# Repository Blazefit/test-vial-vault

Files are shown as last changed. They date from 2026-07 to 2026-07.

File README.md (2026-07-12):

# Testosterone Vial Vault — dark room-temp storage

3D-printable, **light-blocking** storage for testosterone vials + syringes, kept at **room
temperature** (not fridge/freezer). Three sizes at different capacities — **pick one**.

Every pocket is a cell in a **fused honeycomb**: the cell walls overlap and join into one
continuous structure (nothing is a free-standing tube that can snap off), and each cell is
only as **tall as its own vial** so the block stays light. Print in an opaque dark filament
and add the lift-off lid — every vial sits shaded in its own opaque cell.

> **Engineering models, not medical advice.** Verify vial fit with calipers before printing a
> full set (see `PARAMS.md`).

---

## Pick a design

| | **A — Compact** | **B — Standard** | **C — Max** |
|---|---|---|---|
| 10 mL vials | 6 | 8 | 10 |
| 30 mL vials | 3 | 4 | 5 |
| 1 mL vials | 24 | 30 | 36 |
| Syringes (2×N) | 4 | 4 | 6 |
| **Total openings** | **37** | **46** | **57** |
| Block (in) | 6.07 × 6.44 × 3.58 | 7.57 × 6.44 × 3.58 | 8.03 × 7.30 × 3.58 |
| Block (mm) | 154 × 164 × 91 | 192 × 164 × 91 | 204 × 186 × 91 |
| Fits 220 mm bed | ✓ | ✓ | ✓ |
| Light-tightness | genus 0 (sealed) | genus 0 | genus 0 |
| ~PETG tray+lid @15% | ~330 g | ~400 g | ~460 g |

Renders: `renders/{A,C}_top.png` (layout), `{A,C}_tray.png` (3/4), lids, and the fit-audit
cutaway `renders/C_section.png`.

## Why it's strong now (the honeycomb + reinforcement)
The earlier revision used individual tubes with gaps between them — interior tubes were
cantilevered off the base and **snapped off**. This revision packs the cells so their 2 mm
walls **overlap by ~1 mm and fuse** into a continuous honeycomb (verified: every pocket's
nearest neighbour overlaps, `tube-fuse margin = −1.0 mm`). Edge cells fuse into the perimeter
wall; a 5 mm solid base ties every cell bottom together. There are no free-standing walls.

**Reinforced against cold snapping** (the two failure points if it's dropped when cold):
- **Fillet at every cell-to-base junction** (`FILLET = 2.5 mm`, 45°) — spreads the load out of
  the sharp root corner where a wall would otherwise crack off. This is the single biggest
  anti-snap change.
- **Perimeter wall thickened 3 → 4 mm** — it's the tallest thin wall and takes the drops.
- Cost of both: only ~25 g more filament.

**Material matters more than geometry for cold brittleness:** print in **PETG** (tough, stays
that way cold), **not PLA** (PLA is what snaps when cold). If it lives somewhere genuinely cold,
PETG or ASA. Use **4 wall/perimeter lines** in the slicer — the honeycomb's strength is in its walls.

## Why every vial stays dark
1. **Opaque filament** (print black/dark) — walls don't transmit light.
2. **Own opaque cell** — each vial is walled on all sides; the cell rim sits ~8 mm above the
   vial top.
3. **Solid base + perimeter wall + lift-off lid** — the box is closed on all six sides;
   genus 0 means there is not a single through-hole in any wall.

## Stepped cells = lighter
Each cell is only `vial height + 8 mm` tall, so a 45 mm 1 mL vial gets a ~53 mm cell instead
of riding a tall dead pedestal up to the 91 mm rim. That cut the print mass by ~60 % versus a
solid block, while keeping full honeycomb strength.

## Print settings
- **Material:** **PETG** in an **opaque dark color** — light-blocking + cold-tough. Avoid PLA if
  it will ever be cold (that's what snaps).
- **Infill:** 12–15 %. **Walls/perimeters: 4** (the honeycomb strength lives in the walls).
- **Supports:** none. Print tray base-down, lid **roof-down** (skirt up).
- **Bed:** ≤ 220 × 220 mm covers all three. Bore mouths are chamfered for easy drop-in.

## Files
```
scad/vial_vault.scad   parametric model (tray | lid | section) — reads build/<D>_geom.scad
tools/layout.py        layout + geometry engine + all checks (edit fit params HERE)
tools/build_all.sh     render every design to stl/ + renders/
tools/verify_bbox.py   parse STL: bbox match, mesh volume, mass
build/                 auto-generated per-design geometry + part wrappers
stl/  renders/         print files + images
PARAMS.md              every dimension in mm + inches, with the fit assumptions
LOG.md                 iteration log + geometry-check summary
```

## Regenerate / retune
```bash
# edit vial sizes / counts in tools/layout.py, then:
python3 tools/layout.py all      # runs all geometry checks, writes build/
bash   tools/build_all.sh        # renders stl/ + renders/
python3 tools/verify_bbox.py stl/C_tray.stl   # bbox + mass sanity
```

## Verification (final)
All 6 parts render **manifold / NoError**, **genus 0** (no wall openings), and rendered bbox
**matches** the computed envelope. Geometry checks pass: shared webs ≥ 3 mm, every cell fuses
a neighbour or the wall (no free-standing tubes), all pockets inside the faces, tray+lid fit
the bed, 5 mm base under every vial, vials recessed 8 mm. See `LOG.md`.

## Fit status
- **10 mL 21.7 mm · 30 mL 33.1 mm — caliper-verified** (2026-07-12); bores 23.7 / 35.1 mm at a
  1.0 mm radial gap.
- **1 mL 16.0 mm · syringe 14 mm bore × 65 mm — still assumed** (barrel/short syringe, needle off).
  Calipers welcome; both are one-line edits in `tools/layout.py`. Details: `PARAMS.md`.

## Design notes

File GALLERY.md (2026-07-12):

# Vial Vault — Render Gallery

Fused stepped-honeycomb designs, **reinforced against cold snapping** (45° fillet at every
cell-to-base junction + 4 mm perimeter wall). Render colors are the OpenSCAD preview
(teal/blue = walls, orange = interior) — print in **opaque dark PETG** (not PLA — PLA snaps
when cold), 4 wall lines, 15 % infill. All three are 91 mm / 3.58 in tall, fit a 220 mm bed,
and are fully light-tight (genus 0).

---

## A — Compact Honeycomb ⭐ chosen to print
**37 cells:** 6×10 mL · 3×30 mL · 24×1 mL · 4 syringe — **154 × 164 × 91 mm (6.07 × 6.44 × 3.58 in)** — ~320 g PETG
*(10 mL & 30 mL fits caliper-verified 2026-07-12)*

Top-down (layout):
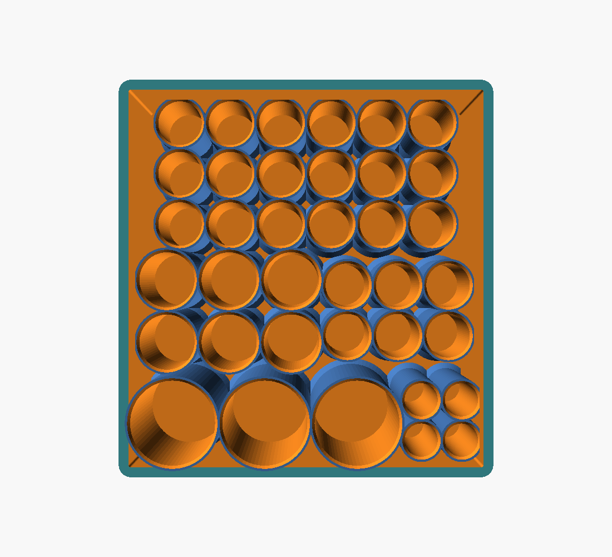
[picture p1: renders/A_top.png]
A top-down


3/4 view (fused honeycomb):
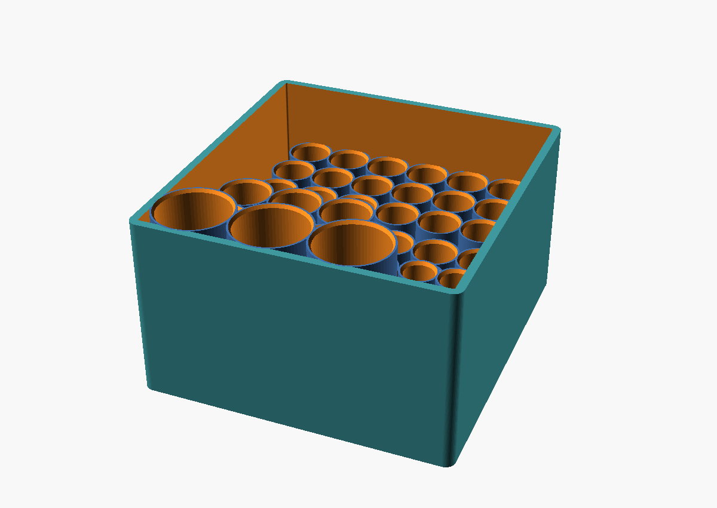
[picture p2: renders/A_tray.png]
A 3/4


Cutaway — vials rest on the base, each in its own cell (red = reference vials):
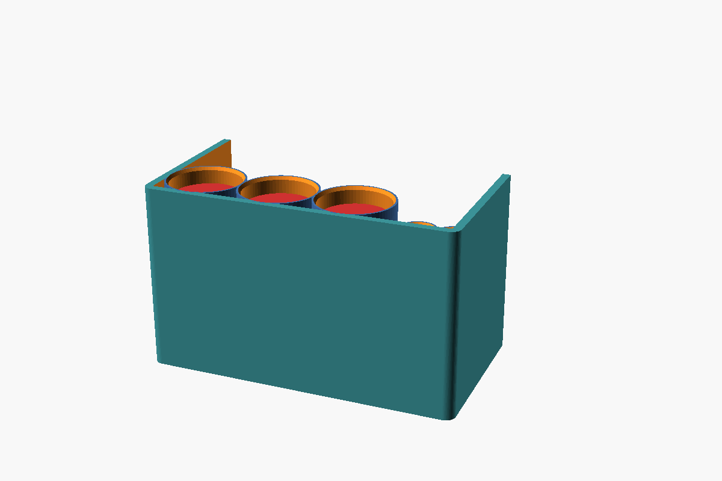
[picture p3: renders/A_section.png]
A cutaway


Lid (prints roof-down):
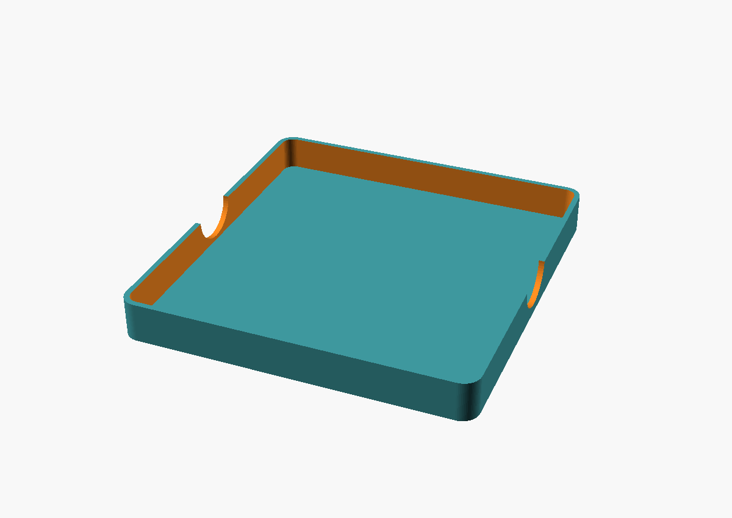
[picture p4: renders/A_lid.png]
A lid


---

## B — Standard Honeycomb
**46 cells:** 8×10 mL · 4×30 mL · 30×1 mL · 4 syringe — **192 × 166 × 91 mm (7.56 × 6.54 × 3.58 in)** — ~400 g PETG

Top-down (layout):
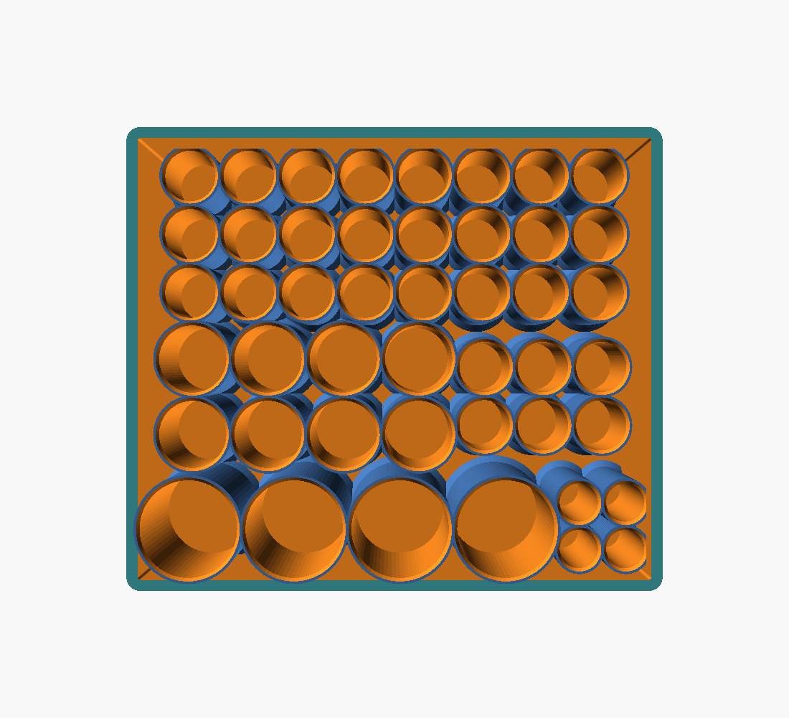
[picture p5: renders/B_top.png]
B top-down


3/4 view:
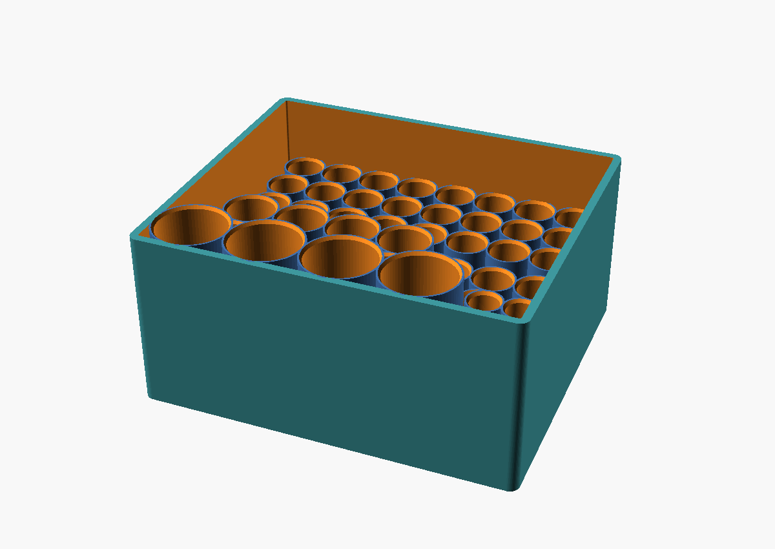
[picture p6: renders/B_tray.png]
B 3/4


---

## C — Max Honeycomb
**57 cells:** 10×10 mL · 5×30 mL · 36×1 mL · 6 syringe — **204 × 188 × 91 mm (8.03 × 7.40 × 3.58 in)** — ~460 g PETG

Top-down (layout):
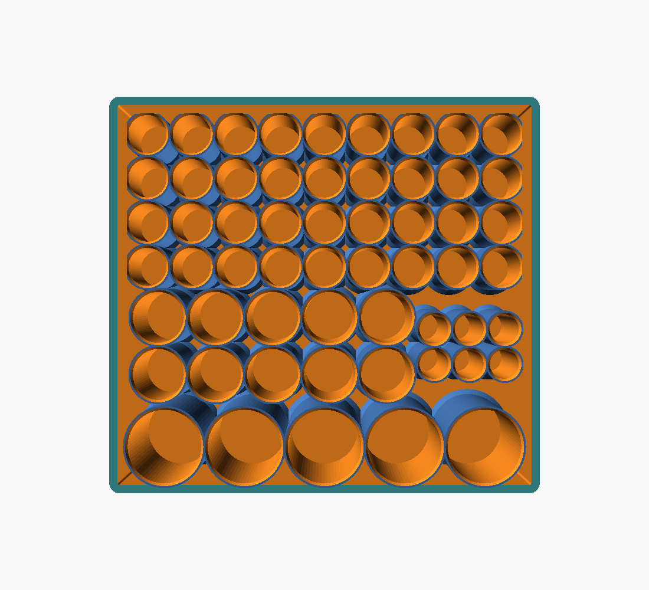
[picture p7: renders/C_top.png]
C top-down


3/4 view (stepped honeycomb):
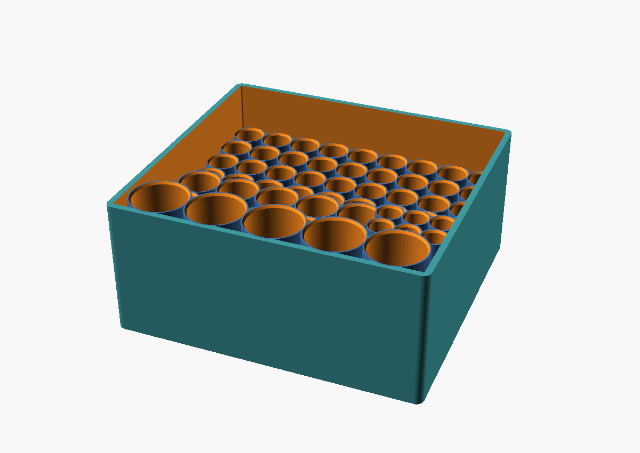
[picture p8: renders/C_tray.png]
C 3/4


Cutaway — vials rest on the base, each in its own cell (red = reference vials):
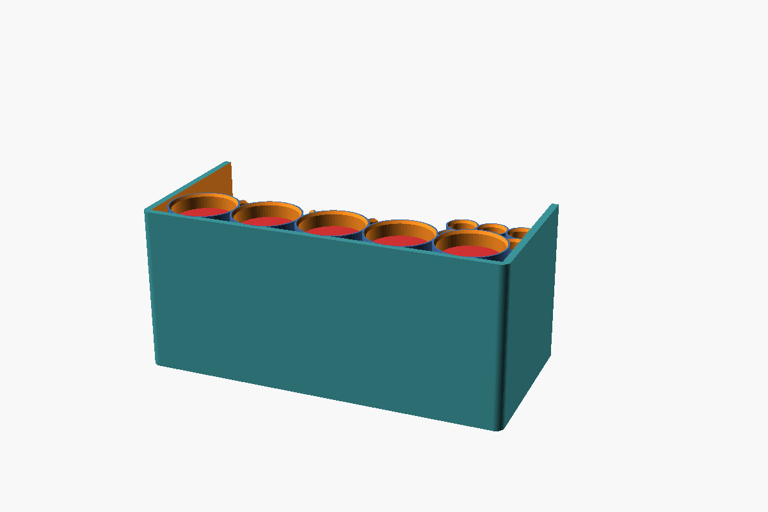
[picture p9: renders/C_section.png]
C cutaway


Lid (prints roof-down):
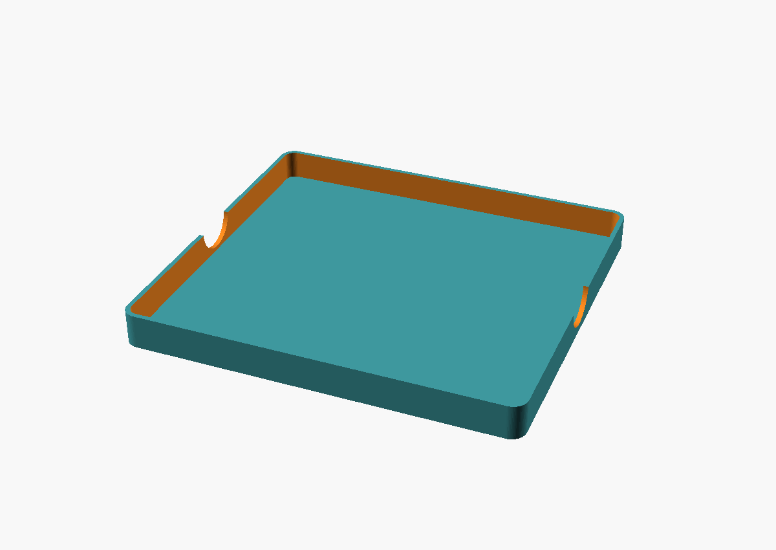
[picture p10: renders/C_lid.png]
C lid


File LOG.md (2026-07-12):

# Iteration Log — Testosterone Vial Vault

Every iteration is gated by `tools/layout.py` (analytic geometry checks) and, where
geometry changed, by `tools/verify_bbox.py` against the freshly rendered STL. "PASS"
means all HARD checks cleared for A, B, and C.

| # | Change | Problem it fixed / why | Result |
|---|---|---|---|
| 1 | Initial row-packed layout + geometry checker | baseline | **FAIL** — 30 mL pedestals 2.0 mm (< 4.0 min); Design C 236 mm long (> 220 bed) |
| 2 | `rim_height` += `INNER_GAP`; rebalanced C (1 mL → 6 cols) | pedestal math dropped the 2 mm bore-bottom gap; C overran bed | **PASS** all three |
| 3 | Rendered STLs, bbox-verified vs computed envelope; C 10 mL → single row of 6 | C lid was 218.4 mm (1.6 mm bed margin — fragile); bbox parser guards silent wrong-part renders | **PASS**, C margin now ~17 mm |
| 4 | Added bore lead-in chamfers (funnel mouth) | vials/syringes catch on a sharp bore lip on the drop-in | **PASS**, manifold NoError |
| 5 | Lid finger-pull scallops + base bottom outer chamfer | lid was hard to lift off flush walls; sharp base edge hurts first-layer adhesion | **PASS**, manifold NoError |
| 6 | Added lid-fit + vial-seating checks to engine | fit was only eyeballed; now proven: 10.0 mm recess, lid clears vial tops | **PASS**, numeric clearances reported |
| 7 | Scallop now points to box centre + breach guard + light-tightness check | uniform +X scallop could pierce the perimeter on an edge pocket; verified each vial fully sleeved | **PASS**, no breach |
| 8 | Cutaway fit-audit render with reference vials | visual proof vials rest on pedestal and sit recessed/shaded | renders/C_section.png |
| 9 | Mesh-volume/mass reporting; rejected side lightening windows | needed print-budget; windows would leak light (kills the "dark" requirement) → opaque walls + 15% infill instead | trays ~275–380 g |
| 10 | Full rebuild + verify all 6 parts (bbox MATCH + manifold + genus) | final gate | **A/B/C tray+lid all PASS**; genus: A_tray 0 (fully light-tight), B/C_tray 2 (only the 2 hand-slots), all lids 0 |

| 11 | Tightened 10 mL & 30 mL clearance 3.0 → 2.0 mm (per-class); 1 mL & syr unchanged | fridge-holder fit was loose (1.5 mm/side); the vault was even looser. Now 1.0 mm/side — snug but one-handed | **PASS**; trays ~4–6 mm smaller, bbox re-MATCH, genus preserved (A 0 / B,C 2) |

| 12 | **Rearchitect: free-standing tubes → monolithic bored block** (denser packing, more openings, mixed-row 2D fill) | user feedback: interior tubes snapped off; too much empty space | **PASS**; A 18→37, C 25→57 openings — but solid block ~700 g (A) / ~980 g (C): too heavy |
| 13 | **Stepped merged-tube honeycomb**: cells fuse (walls overlap 1 mm), each cell only as tall as its vial; scallops dropped | solid block too heavy; still needed fused (not free-standing) walls + light | **PASS**, genus 0 all parts; mass down ~60% (A ~264 g, C ~383 g tray); `tube-fuse margin −1.0 mm` = nothing free-standing |

| 14 | **Reinforce vs cold-snap:** 45° fillet at every cell→base junction + perimeter wall 3→4 mm; recommend PETG (not PLA) + 4 walls | user: use the lightest that won't snap, reinforce if cold-prone | **PASS**, genus 0; +~25 g only (A 264→286, C 383→409 g tray); footprints unchanged |

| 15 | **Caliper-verified 10 mL (21.7 mm) & 30 mL (33.1 mm)** ODs → bores 23.7 / 35.1 mm; Design A chosen for print | Jason measured his vials + picked A | **PASS**, A re-exported: 154 × 164 × 91 mm, genus 0, bbox MATCH, ~282 g tray |

## Geometry-check summary (final — fused honeycomb)
All HARD checks clear for A, B, C:
- shared web between adjacent bores ≥ 3.0 mm
- **fusion:** every cell overlaps a neighbour or the perimeter wall (`tube-fuse margin −1.0 mm`)
  → no free-standing tubes (the thing that snapped off before)
- every bore ≥ 4.5 mm from the outer face; block **and** lid fit the 220 × 220 mm bed
- 5 mm solid base under every vial; vials recessed 8 mm in their own cell
- light-tightness: all 6 parts **genus 0** — not one through-hole in any wall

## Notes on the iterations
1–10 built and hardened the original per-tube design (real geometry fixes: pedestal
thickness, bed overrun, thin margins, fit/light-tightness). 11 tightened the 10/30 mL fits.
12–13 are the architecture change from user feedback: tubes snapped off and left dead space,
so it was reworked into a denser **fused honeycomb** (12), then made **stepped + light** (13).
Re-run any of it with `python3 tools/layout.py all` then `bash tools/build_all.sh`.

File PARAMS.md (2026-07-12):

# Parameters & Dimensions

All geometry is generated from `tools/layout.py`. Edit the values there and re-run to
regenerate every design. Dimensions below are given in **mm and inches**.

## ⚠️ Fit assumptions — CALIPER-VERIFY THESE FIRST

These are the numbers most likely to be wrong for *your* vials. They are set generously,
but measure your actual product and edit `VIAL` / `DIA_CLEAR` in `tools/layout.py`.

| Item | OD | Height | Bore (hole) cut | Radial gap | Notes |
|---|---|---|---|---|---|
| **1 mL vial** | 16.0 mm (0.63 in) *(assumed)* | 45 mm (1.77 in) | 19.0 mm (0.75 in) | 1.5 mm/side | roomy on purpose — doubles as finger-grab room for a tiny vial |
| **10 mL vial** | **21.7 mm** ✓calipered | 55 mm (2.17 in) | **23.7 mm (0.93 in)** | **1.0 mm/side** | measured 2026-07-12 |
| **30 mL vial** | **33.1 mm** ✓calipered | 78 mm (3.07 in) | **35.1 mm (1.38 in)** | **1.0 mm/side** | measured 2026-07-12 |
| **Syringe (2×2)** | 14.0 mm bore *(assumed)* | 65 mm (2.56 in) | 14.0 mm (0.55 in) | — | **assumes barrel / short syringe standing, plunger up** |

**Syringe caveat:** a 3 mL syringe *with a long needle + cap* is ~90–115 mm — taller than
the box. The 2×2 pockets are sized for **barrels stored plunger-up (needle off)**. If you
want to store full needled syringes, raise `VIAL["syr"]["h"]` and the box grows to suit.

Clearance is **per-class** now (`VIAL[...]["clear"]` = mm added to OD → bore). The 10 mL and
30 mL were tightened to a **1.0 mm radial gap** — snug but drops in/out one-handed, and still
forgiving of the unverified OD assumption. Bore mouths are chamfered as a funnel.
**Want it tighter still?** Once you caliper a real vial, you can go to `clear = 1.5`
(0.75 mm/side) for a nicer fit — but tightening + a wrong OD guess = won't fit, so verify OD first.

## Structural parameters — fused honeycomb (`tools/layout.py`)

| Param | Value | Meaning |
|---|---|---|
| `PWALL` | 2.0 mm | cell wall. Tubes are packed so walls **overlap ~1 mm and fuse** (2·PWALL > web) |
| `WEB_MIN` | 3.0 mm | solid between two adjacent bores (the shared, fused honeycomb wall) |
| `WALL` | 4.0 mm | full-height perimeter wall — thickened 3→4 mm (reinforcement) |
| `FILLET` | 2.5 mm | 45° fillet at every cell-to-base junction — the anti-snap stress relief |
| `EDGE_MIN` | 4.5 mm | bore edge → outer face (chosen so edge cells fuse into the wall) |
| `BASE_T` | 5.0 mm | solid base slab — every vial rests on it; ties all cell bottoms together |
| `RECESS` | 8.0 mm | vial-top recess below its own cell rim (shade; cell is only vial+8 mm tall) |
| `ROW_GAP`/`COL_GAP` | 3.0 mm | gaps between grids — ≤ 2·PWALL so cells fuse across them too |
| `SKIRT_H` | 16.0 mm | how far the lid skirt grips down over the block |
| `LID_GAP` | 0.4 mm | lid-to-block radial clearance |
| `BED_X × BED_Y` | 220 × 220 mm | usable print bed (edit to your printer) |

**Structure check:** `tube-fuse margin` reports the worst-case nearest-neighbour tube overlap;
`−1.0 mm` means every cell overlaps a neighbour (or the wall) — no free-standing tubes.

## Final envelope sizes (mm / inches)

| Design | Contents | Block W × L × H (mm) | Block (in) | Lid W × L × H (mm) | Lid (in) | ~PETG (tray+lid) |
|---|---|---|---|---|---|---|
| **A — Compact** | 6×10 mL, 3×30 mL, 24×1 mL, 4 syr | 154 × 164 × 91 | 6.07 × 6.44 × 3.58 | 160 × 170 × 18.6 | 6.31 × 6.67 × 0.73 | ~320 g |
| **B — Standard** | 8×10 mL, 4×30 mL, 30×1 mL, 4 syr | 192 × 164 × 91 | 7.57 × 6.44 × 3.58 | 198 × 170 × 18.6 | 7.81 × 6.67 × 0.73 | ~395 g |
| **C — Max** | 10×10 mL, 5×30 mL, 36×1 mL, 6 syr | 204 × 186 × 91 | 8.03 × 7.30 × 3.58 | 210 × 192 × 18.6 | 8.27 × 7.54 × 0.73 | ~455 g |

*(10 mL & 30 mL now caliper-verified; sizes updated from the earlier estimate.)*

All three are **91 mm (3.58 in) tall** (set by the 30 mL vial). Shorter vials get shorter cells
inside, so the block is much lighter than a solid one. Every block + its lid fits a 220 mm bed.
Mass is a rough estimate at 15 % infill — slice it for the real number.

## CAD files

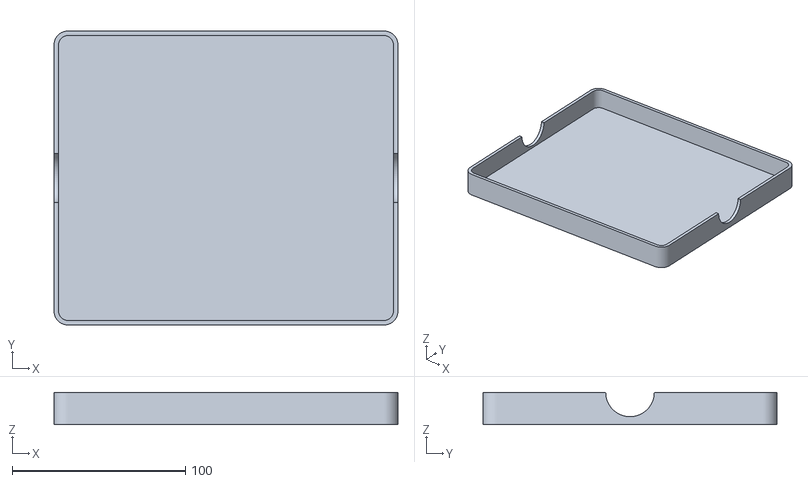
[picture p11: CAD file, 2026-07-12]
stl/B_lid.stl
198.4 x 169.5 x 18.6

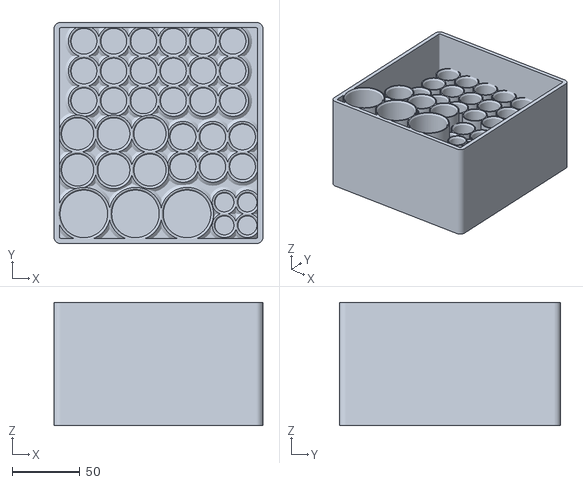
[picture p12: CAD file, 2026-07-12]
stl/A_tray.stl
154.3 x 163.5 x 91.0

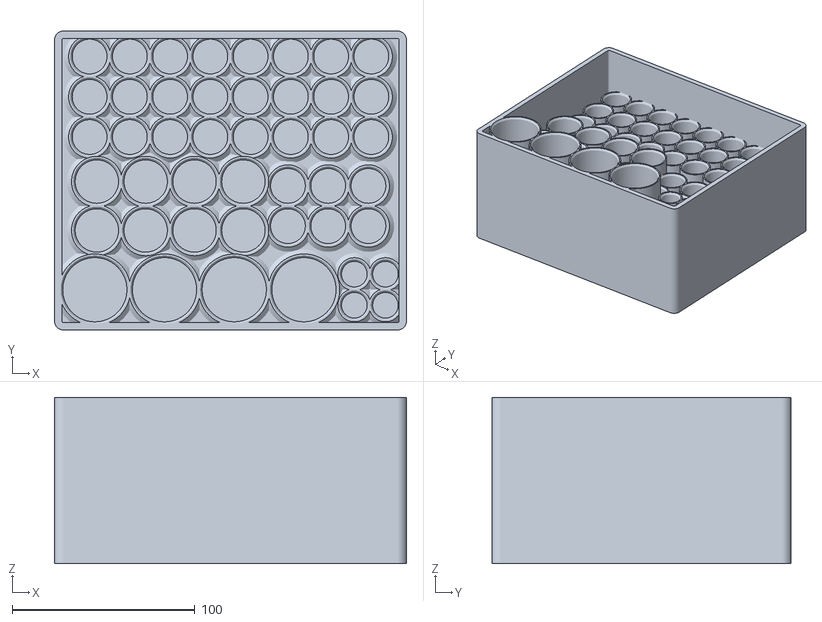
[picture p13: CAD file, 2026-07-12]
stl/B_tray.stl
192.4 x 163.5 x 91.0

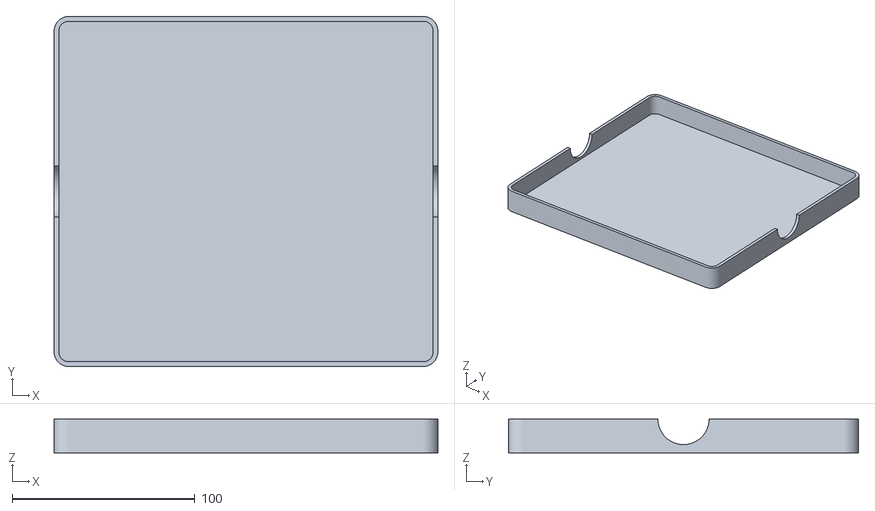
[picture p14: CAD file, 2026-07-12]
stl/C_lid.stl
210.0 x 191.5 x 18.6

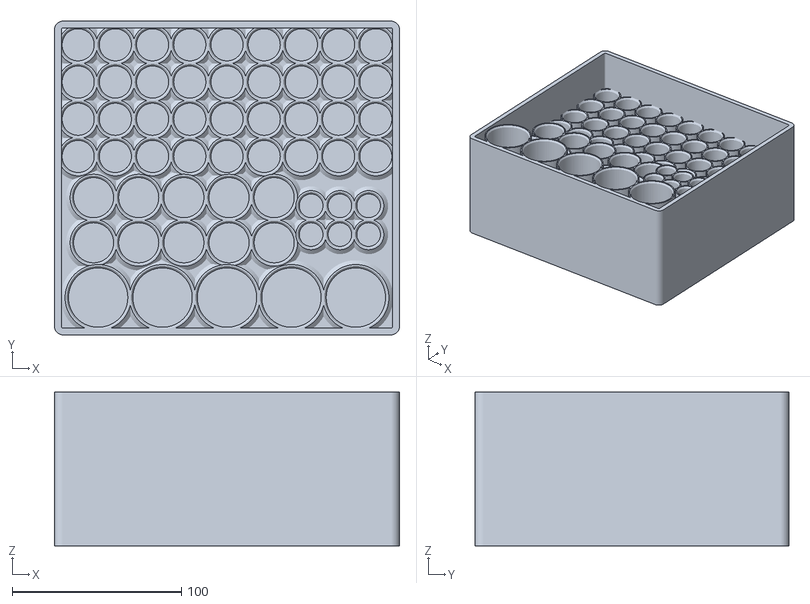
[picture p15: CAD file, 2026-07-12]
stl/C_tray.stl
204.0 x 185.5 x 91.0

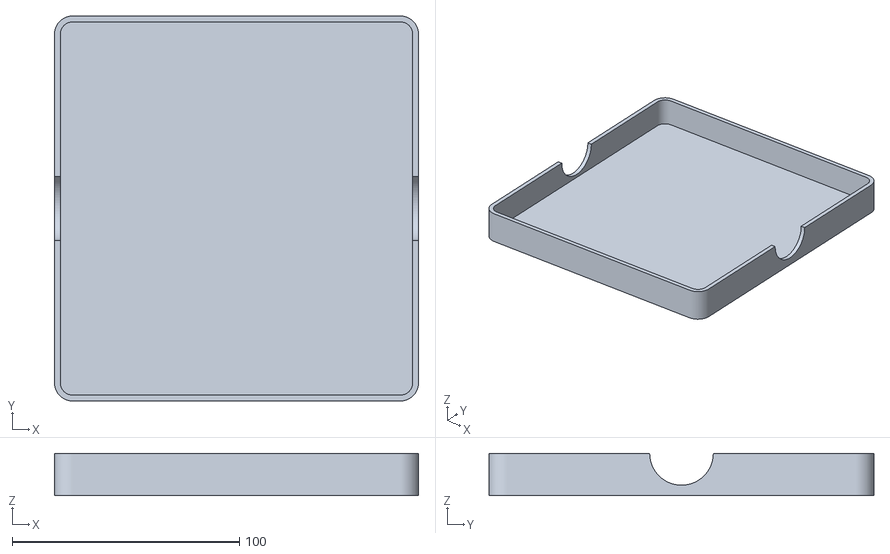
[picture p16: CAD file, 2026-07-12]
stl/A_lid.stl
160.3 x 169.5 x 18.6

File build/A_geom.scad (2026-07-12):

// AUTO-GENERATED by layout.py for design A. Merged-tube honeycomb rev.
DESIGN = "A";
OUTER_W = 154.3;
OUTER_L = 163.5;
RIM_H = 91.0;
BASE_T = 5.0;
WALL = 4.0;
PWALL = 2.0;
FILLET = 2.5;
CORNER_R = 5.0;
RECESS = 8.0;
LID_GAP = 0.4;
SKIRT_W = 2.6;
SKIRT_H = 16.0;
ROOF_T = 2.6;
FINGER_SCALLOP = false;
// POCKETS = [x, y, bore, depth, is_small, scallop_deg]  (cell height = BASE_T+depth)
POCKETS = [
  [-55.1, -59.7, 35.1, 86.0, 0, 47.3],
  [-17.0, -59.7, 35.1, 86.0, 0, 74.1],
  [21.1, -59.7, 35.1, 86.0, 0, 109.5],
  [48.65, -68.2, 14.0, 73.0, 1, 125.5],
  [65.65, -68.2, 14.0, 73.0, 1, 133.9],
  [48.65, -51.2, 14.0, 73.0, 1, 133.5],
  [65.65, -51.2, 14.0, 73.0, 1, 142.0],
  [-59.7, -27.3, 23.7, 63.0, 0, 24.6],
  [-33.0, -27.3, 23.7, 63.0, 0, 39.6],
  [-6.3, -27.3, 23.7, 63.0, 0, 77.0],
  [-59.7, -0.6, 23.7, 63.0, 0, 0.6],
  [-33.0, -0.6, 23.7, 63.0, 0, 1.0],
  [-6.3, -0.6, 23.7, 63.0, 0, 5.4],
  [18.05, -24.95, 19.0, 53.0, 1, 125.9],
  [40.05, -24.95, 19.0, 53.0, 1, 148.1],
  [62.05, -24.95, 19.0, 53.0, 1, 158.1],
  [18.05, -2.95, 19.0, 53.0, 1, 170.7],
  [40.05, -2.95, 19.0, 53.0, 1, 175.8],
  [62.05, -2.95, 19.0, 53.0, 1, 177.3],
  [-55.0, 23.75, 19.0, 53.0, 1, -23.4],
  [-33.0, 23.75, 19.0, 53.0, 1, -35.7],
  [-11.0, 23.75, 19.0, 53.0, 1, -65.1],
  [11.0, 23.75, 19.0, 53.0, 1, -114.9],
  [33.0, 23.75, 19.0, 53.0, 1, -144.3],
  [55.0, 23.75, 19.0, 53.0, 1, -156.6],
  [-55.0, 45.75, 19.0, 53.0, 1, -39.8],
  [-33.0, 45.75, 19.0, 53.0, 1, -54.2],
  [-11.0, 45.75, 19.0, 53.0, 1, -76.5],
  [11.0, 45.75, 19.0, 53.0, 1, -103.5],
  [33.0, 45.75, 19.0, 53.0, 1, -125.8],
  [55.0, 45.75, 19.0, 53.0, 1, -140.2],
  [-55.0, 67.75, 19.0, 53.0, 1, -50.9],
  [-33.0, 67.75, 19.0, 53.0, 1, -64.0],
  [-11.0, 67.75, 19.0, 53.0, 1, -80.8],
  [11.0, 67.75, 19.0, 53.0, 1, -99.2],
  [33.0, 67.75, 19.0, 53.0, 1, -116.0],
  [55.0, 67.75, 19.0, 53.0, 1, -129.1],
];

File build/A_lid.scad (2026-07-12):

PART = "lid";
include <A_geom.scad>
include <../scad/vial_vault.scad>

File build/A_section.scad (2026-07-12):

PART="section";
include <A_geom.scad>
include <../scad/vial_vault.scad>

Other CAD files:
build/A_tray.scad
build/B_geom.scad
build/B_lid.scad
build/B_tray.scad
build/C_geom.scad
build/C_lid.scad
build/C_section.scad
build/C_tray.scad
scad/vial_vault.scad

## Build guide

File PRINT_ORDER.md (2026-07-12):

# Print Order — Design A (Vial Vault, Compact)

Copy/paste this to the print service. It's a functional storage box that must be **opaque**
(blocks light) and **not brittle** (must not snap, including in the cold).

## Files (2 parts, print 1 of each)
- **Tray ×1** — `stl/A_tray.stl` — https://raw.githubusercontent.com/Blazefit/test-vial-vault/main/stl/A_tray.stl
- **Lid ×1** — `stl/A_lid.stl` — https://raw.githubusercontent.com/Blazefit/test-vial-vault/main/stl/A_lid.stl
- Units: **millimeters**. Tray bounding box 154 × 164 × 91 mm. Lid 160 × 170 × 19 mm.

## Material — pick in this order
1. **BEST: MJF or SLS Nylon (PA12), black/grey.** Strong in every direction (no weak layer to
   snap off), opaque, matte, tough in the cold. Ideal for this part. ~200–350 g of material.
2. **GOOD / cheaper: FDM in PETG, black.** Ask for **≥3 perimeters/walls, 15–20% infill, no
   supports.** Tough and opaque; slightly weaker across layer lines than nylon but fine.
3. **AVOID: SLA / DLP resin, and PLA.** Both are **brittle and snap when cold** — do not use for
   this part, even if offered as "black."

Any opaque dark color is fine — the point is that light can't get through the walls.

## Orientation & notes
- **FDM:** tray printed **flat on its base** (open cells up); lid printed **flat, roof-down**
  (skirt pointing up). No supports needed — everything is self-supporting.
- **MJF/SLS:** orientation doesn't matter (isotropic) — no supports, no notes needed.
- All walls are ≥ 2 mm and the base is 5 mm, so it clears every process's minimum-wall rule.
- Holes are cut with a 1.0 mm/side clearance on the vials, which absorbs normal process
  tolerance — no need to scale the part.

## What it holds (so the shop knows it's a real functional part)
37 pockets: 6× 10 mL vials, 3× 30 mL vials, 24× 1 mL vials, 4× syringes, plus a lift-off lid.

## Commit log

2026-07-12 Testosterone vial vault: 3 dark room-temp storage designs (A/B/C)
    Parametric OpenSCAD holder for testosterone vials + syringes, stored at room
    temp and shaded from light. Three capacities to choose from:
    A Compact 4x10mL 2x30mL 8x1mL + 2x2 syringe 135.8x182.2x95 mm
    B Caddy 5x10mL 2x30mL 10x1mL + 2x2 syringe 166.4x182.2x95 mm
    C Max 6x10mL 3x30mL 12x1mL + 2x2 syringe 197.0x182.2x95 mm
    Each vial sits in its own opaque sleeve (light-tight) with a lift-off lid.
    layout.py is the single source of truth: computes pocket placement and runs
    all geometry checks (pocket walls, perimeter containment, 220mm bed fit,
    pedestal thickness, vial seating, scallop breach, light-tightness).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
    [A_geom.scad, A_lid.scad, A_lid.stl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]
2026-07-12 Tighten 10 mL & 30 mL vial fits (clearance 3.0 -> 2.0 mm)
    Fridge-holder fit was loose; the vault inherited it. Make clearance per-class
    and drop 10 mL/30 mL to a 1.0 mm radial gap (bores 26->25 and 36->35 mm).
    1 mL kept roomy (finger-grab room); syringes unchanged. Trays shrank ~4-6 mm.
    Re-verified: all checks PASS, rendered bbox re-MATCHes, light-tightness genus
    preserved (A_tray 0; B/C_tray 2 hand-slots).
    [A_geom.scad, A_lid.stl, A_tray.stl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]
2026-07-12 Add top-down renders; refresh A/C render set
    Top-down views (A_top, C_top) for judging pocket layout, plus refreshed 3/4,
    lid, and cutaway renders from the tightened geometry.
2026-07-12 Rearchitect to fused stepped honeycomb (strength + density + lighter)
    User feedback: free-standing tubes snapped off, and layout left too much empty
    space. Reworked so pockets are cells whose 2mm walls overlap ~1mm and FUSE into
    one continuous honeycomb (nothing free-standing; verified tube-fuse margin -1.0mm),
    tied by a 5mm base + full-height perimeter wall. Mixed-row 2D packing nearly
    doubles capacity in a similar footprint:
    A 37 openings (6x10 3x30 24x1 +4syr) 156x166x91 mm
    B 46 openings (8x10 4x30 30x1 +4syr) 192x166x91 mm
    C 57 openings (10x10 5x30 36x1 +6syr) 204x188x91 mm
    Each cell is only as tall as its own vial (stepped), cutting print mass ~60% vs a
    solid block (C ~980g -> ~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
    [A_geom.scad, A_lid.stl, A_tray.stl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]
2026-07-12 Add GALLERY.md — all honeycomb renders inline on one GitHub page
2026-07-12 Reinforce against cold-snap: base fillets + 4mm perimeter wall
    Added a 45-deg fillet at every cell-to-base junction (kills the stress riser where
    a wall snaps off its root) and thickened the perimeter wall 3->4mm. Cost ~25g only
    (A ~286g, C ~409g tray). Footprints/counts unchanged, genus 0, bbox matches.
    Docs now call for PETG (not PLA) + 4 wall lines for cold toughness.
    [A_geom.scad, A_tray.stl, B_geom.scad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]
2026-07-12 Apply caliper-verified vial ODs (10mL 21.7, 30mL 33.1); Design A chosen
    Jason measured his vials: 10 mL 21.7 mm, 30 mL 33.1 mm -> bores 23.7 / 35.1 mm at
    1.0 mm radial gap. Regenerated all designs; Design A picked for print
    (154 x 164 x 91 mm, ~282 g tray, genus 0, bbox MATCH). 1 mL + syringe still assumed.
    [A_geom.scad, A_lid.stl, A_section.scad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]
2026-07-12 Add PRINT_ORDER.md — service-bureau handoff spec for Design A
    Jason is outsourcing (no printer). One-page spec: files, material ranking
    (MJF/SLS nylon best; PETG good; avoid resin/PLA as brittle-when-cold),
    orientation, tolerances.
